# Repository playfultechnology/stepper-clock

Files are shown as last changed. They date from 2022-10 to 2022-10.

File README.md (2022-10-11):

# stepper-clock
A clock mechanism in which hour and minute hands driven independently by two 28BJY-48 stepper motors

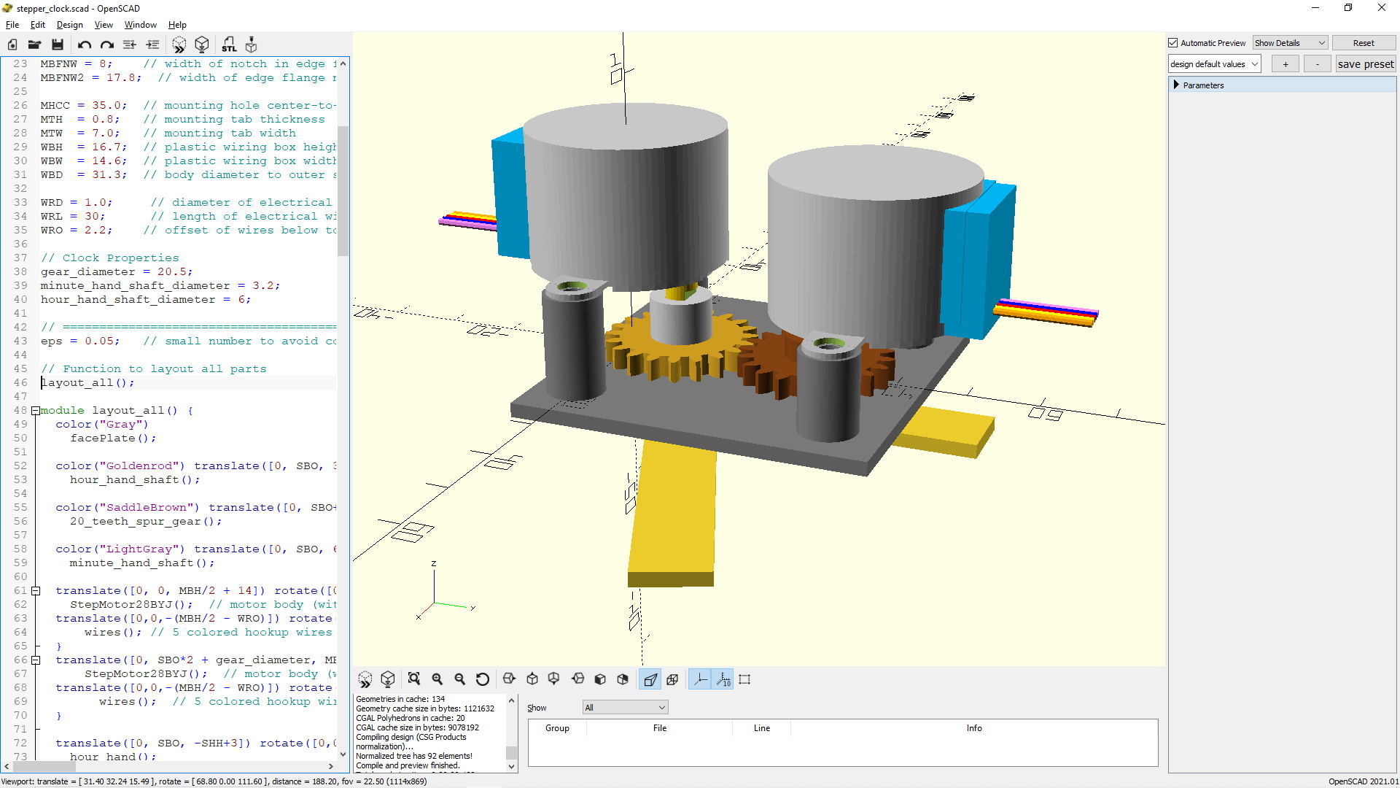
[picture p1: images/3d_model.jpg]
3D model


## Notes
28BJY-48 motors are very cheap, easy to source and use, and often found in hobbyist projects. They can be driven at 5V with 4 signal lines from an Arduino or other microprocessor via a ULN2003 driver. However, they have some noticeable limitations:
 - The gear ratio can differ between units; it generally seems to be either 4076 or 4096 steps per rotation. Note that neither of these numbers is exactly divisible by 360, nor 60, nor 12, so it is impossible to move the motor to an exact hour, minute, or degree of a circle.
 - Worse still, sometimes the gear ratio is not even a whole integer number of steps per revolution: meaning you cannot even rotate one full revolution accurately. 

These motors are intended for opening small vents in car air conditioning / heating systems. As such, they are not designed for continuous rotation, and accumulated error over multiple rotations is not considered a flaw in their design. However, that can present issues if you were trying to use these for accurate movement of clock hands. 
In my use case, this mechanism was for independent movement of hands in an escape room clock mechanism, so accuracy was not a crucial factor. For greater precision, it might be preferable to use a NEMA stepper instead which generally use exactly 200 steps per 360° degrees rotation - i.e. exactly 1.8° per step. However, they are significantly bulkier and more expensive.

Neither 28BJY-48 or NEMA17 stepper motors have any built-in position feedback mechanism. So, in order to be able to reset the hands to a known position, it might be desirable to add a small magnet to the cogs/hands, and a hall sensor to detect a "zero" point as they pass.

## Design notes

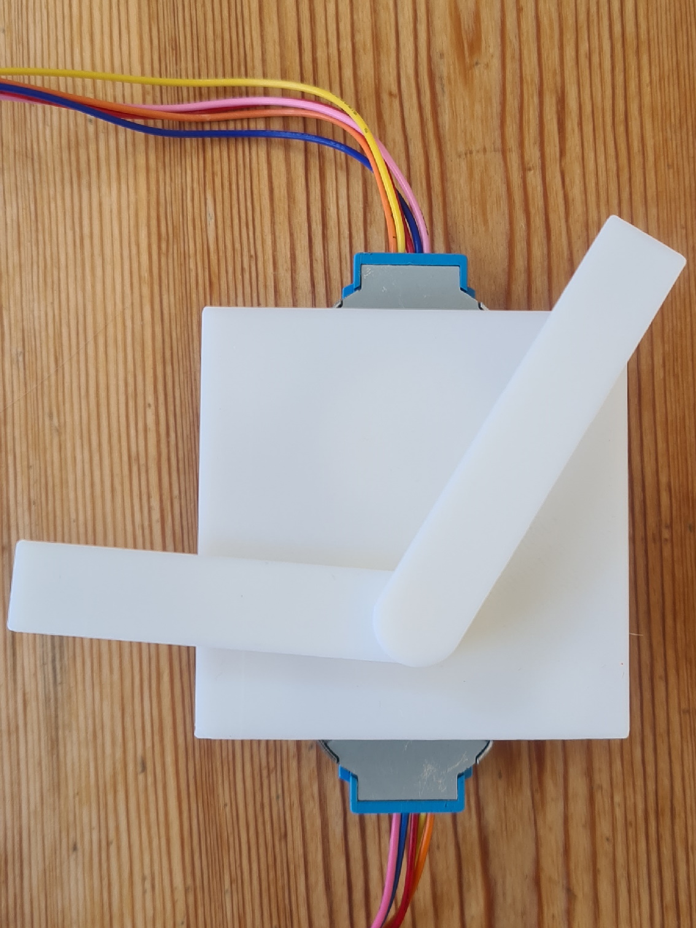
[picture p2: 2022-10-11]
images/clock.jpg

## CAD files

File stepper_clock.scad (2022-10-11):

/**
 * Stepper motor clock mechanism
 * (c) 2022 Alastair Aitchison, Playful Technology
 */

// Gear generator https://github.com/chrisspen/gears
// (English translation of https://www.thingiverse.com/thing:1604369)
include <gears/gears.scad>

// Stepper Motor Properties
MBH = 18.8;   // motor body height
MBD = 28.25;  // motor body OD
SBD = 9.1;    // shaft boss OD
SBH = 1.45;   // shaft boss height above motor body
SBO = 7.875;  // offset of shaft/boss center from motor center
SHD = 4.93;   // motor shaft OD
SHDF = 3.0;   // motor shaft diameter, across flats
SHHF = 6.0;   // motor shaft flats height, or depth in from end
SHH = 9.75;   // height of shaft above motor body 

MBFH = 0.7;   // height of body edge flange protruding above surface
MBFW = 1.0;   // width of edge flange
MBFNW = 8;    // width of notch in edge flange
MBFNW2 = 17.8;  // width of edge flange notch above wiring box

MHCC = 35.0;  // mounting hole center-to-center
MTH  = 0.8;   // mounting tab thickness
MTW  = 7.0;   // mounting tab width
WBH  = 16.7;  // plastic wiring box height
WBW  = 14.6;  // plastic wiring box width
WBD  = 31.3;  // body diameter to outer surface of wiring box

WRD = 1.0;     // diameter of electrical wires
WRL = 30;      // length of electrical wires
WRO = 2.2;		// offset of wires below top motor surface

// Clock Properties
gear_diameter = 20.5;
minute_hand_shaft_diameter = 3.2;
hour_hand_shaft_diameter = 6;

// =========================================================
eps = 0.05;   // small number to avoid coincident faces

// Function to layout all parts
layout_all();

module layout_all() {
  color("Gray")
    facePlate();

  color("Goldenrod") translate([0, SBO, 3]) rotate([0,180,0])
    hour_hand_shaft();
    
  color("SaddleBrown") translate([0, SBO+gear_diameter, 0]) rotate([0,0,0 -360/20/2 *3 ]) 
    20_teeth_spur_gear();

  color("LightGray") translate([0, SBO, 6+3]) rotate([0,180,90])
    minute_hand_shaft();
    
  translate([0, 0, MBH/2 + 14]) rotate([0, 0, 90]) {
    StepMotor28BYJ();  // motor body (without wires)
  translate([0,0,-(MBH/2 - WRO)]) rotate([0,-90,0])  
      wires(); // 5 colored hookup wires
  }
  translate([0, SBO*2 + gear_diameter, MBH/2 + 11]) rotate([0,0,-90]) {
      StepMotor28BYJ();  // motor body (without wires)
  translate([0,0,-(MBH/2 - WRO)]) rotate([0,-90,0])  
        wires();  // 5 colored hookup wires
  }
  
  translate([0, SBO, -SHH+3]) rotate([0,0,90])
    hour_hand();
  translate([0, SBO, -SHH]) rotate([0,0,22.5])
    minute_hand(); 
}


module minute_hand() {
  adjust = 0.1;
  hand_length = 50;
  
  difference(){
    union() {
      cylinder(d=10,h=4);
      translate([0,-5,0])
        cube([hand_length,10,2]);
    }
    translate([0,0,4-3])
    cylinder(d=minute_hand_shaft_diameter + adjust, h=3);
  }
}

module hour_hand() {
  adjust = -0.1;
  hand_length = 45;
  
  difference() {
    union() {
      cylinder(d=10,h=4);
      translate([0,-5,0])
        cube([hand_length,10,2]);
    }
    cylinder(d=hour_hand_shaft_diameter-1, h=4+eps);
    translate([0,0,0.4])
    cylinder(d=hour_hand_shaft_diameter + adjust, h=4-0.4+eps);
  }
}


module minute_hand_shaft() {
  expand = 0.15;
  shaft_depth = 5;

  difference() {
    union() {
      cylinder(d=8.9, h=6);
        translate([0,0,6])
          cylinder(d=3.2, h=12.5);
    }
    translate([0,0,-eps]) {
      intersection() {
        cylinder(d=SHD+expand, h=shaft_depth, $fn=40);
        translate([0,0, shaft_depth/2])
          cube([SHDF+expand,SHHF+expand,shaft_depth],center=true);
      }
    }
  }
}

module hour_hand_shaft() {
  difference() {
    union() {
      spur_gear (modul=1, tooth_number=20, width=3, bore=0, pressure_angle=20, helix_angle=0, optimized=false);
        translate([0,0,3])
          cylinder(d=6, h=6.5);
    }
    translate([0,0,-eps])
      cylinder(d=3.5, h=10);
  }
}

module 20_teeth_spur_gear() {
  expand = 0.1;
  shaft_depth = 5;
  
  difference() {
    union(){
      spur_gear (modul=1, tooth_number=20, width=3, bore=0, pressure_angle=20, helix_angle=0, optimized=false);
      translate([0,0,3]) {
        cylinder(d=8.9, h=3.05);
      }
    }
    translate([0,0,6.05-shaft_depth+eps])
      rotate([0,0,360/20/2*93])
        intersection() {
          cylinder(d=SHD+expand, h=shaft_depth, $fn=40);
            translate([0,0, shaft_depth/2])
            cube([SHDF+expand,SHHF+expand,shaft_depth],center=true);
        }
  }
}

module facePlate() {
  $fn=100;

  width= 50;
  length = 50;
  depth = 2;

  difference() {
    // Base
    translate([-width/2,-6,-depth])  
      cube([width,length,depth]);
    
    // Hole for shaft
    translate([0,SBO,-30]){
      cylinder(h=65, d=6.4);
    } 
  }
  // Standoffs
  translate([-MHCC/2, 0, 0]) {
    difference() {
      cylinder(h=14, d=8.1);
      cylinder(h=14+1, d=3);
    }
  }
  translate([MHCC/2, 0, 0]) {
    difference() {
      cylinder(h=14, d=8.1);
      cylinder(h=14+1, d=3);
    }
  }
  translate([-MHCC/2, SBO*2 + gear_diameter, 0]) {
    difference() {  
      cylinder(h=11, d=8.1);
      cylinder(h=11+1, d=3);
    }
  }
  translate([MHCC/2, SBO*2 + gear_diameter, 0]) {
    difference() {
      cylinder(h=11, d=8.1);
      cylinder(h=11+1, d=3);
    }
  }
}

// 28BYJ-48 model by RGriffoGoes, www.thingiverse.com/thing:204734
module StepMotor28BYJ() {
  difference(){
    union(){
	   color("LightGray") translate([0,0,-(MBH+MBFH)/2])
		  difference() {  // flange at top rim
         cylinder(h = MBFH+eps, r = MBD/2, center = true, $fn = 50);
         cylinder(h = MBFH+2*eps, r = (MBD-MBFW)/2, center = true, $fn = 32);
			cube([MBFNW,MHCC,MBFH*2],center=true); // notches in rim
			cube([MBD+2*MBFW,SBD,MBFH*2],center=true);
		   translate([-MBD/2,0,0]) cube([MBD,MBFNW2,MBFH*2],center=true);
        }
		color("LightGray") // motor body
			cylinder(h = MBH, r = MBD/2, center = true, $fn = 100);
		color("LightGray") translate([SBO,0,-SBH])	// shaft boss
			cylinder(h = MBH, r = SBD/2, center = true, $fn = 32);

		translate([SBO,0,-SHH])	// motor shaft
      difference() {
        color("gold") cylinder(h = MBH, r = SHD/2, center = true, $fn = 32);
				// shaft flats
        translate([(SHD+SHDF)/2,0,-(eps+MBH-SHHF)/2]) 
				cube([SHD,SHD,SHHF], center = true);
        translate([-(SHD+SHDF)/2,0,-(eps+MBH-SHHF)/2]) 
				cube([SHD,SHD,SHHF], center = true);
      }

		color("Silver") translate([0,0,-(MBH-MTH-eps)/2]) // mounting tab 
			cube([MTW,MHCC,MTH], center = true);				
		color("Silver") translate([0,MHCC/2,-(MBH-MTH)/2]) // mt.tab rounded end
			cylinder(h = MTH, r = MTW/2, center = true, $fn = 32);
		color("Silver") translate([0,-MHCC/2,-(MBH-MTH)/2]) // mt.tab rounded end
			cylinder(h = MTH, r = MTW/2, center = true, $fn = 32);

		color("DeepSkyBlue") translate([-(WBD-MBD),0,eps-(MBH-WBH)/2]) // plastic wire box
			cube([MBD,WBW,WBH], center = true);
	   color("DeepSkyBlue") translate([-2,0,0])	
			cube([24.5,16,15], center = true);
		}

    // mounting holes in tabs on side
		translate([0,MHCC/2,-MBH/2])	
				cylinder(h = 2, r = 2, center = true, $fn = 32);
		translate([0,-MHCC/2,-MBH/2])	
				cylinder(h = 2, r = 2, center = true, $fn = 32);
		}
	}
module wires() {
  color("orange") translate([0,WRD*2,0]) cylinder(h=WRL,r=WRD/2, $fn = 7);
  color("yellow") translate([0,WRD*1,0]) cylinder(h=WRL,r=WRD/2, $fn = 7);   
  color("red") translate([0,0,0]) cylinder(h=WRL,r=WRD/2, $fn = 7);
  color("blue") translate([0,-WRD*1,0]) cylinder(h=WRL,r=WRD/2, $fn = 7);
  color("violet") translate([0,-WRD*2,0]) cylinder(h=WRL,r=WRD/2, $fn = 7);
}  

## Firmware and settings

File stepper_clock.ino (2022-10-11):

// DEFINES
// Some discrepancy as to whether 4076 or 4096
// See https://www.makerguides.com/28byj-48-stepper-motor-arduino-tutorial/
#define NUM_STEPS 4096.0  
#define DEBUG

// INCLUDES
// https://www.airspayce.com/mikem/arduino/AccelStepper/
#include <AccelStepper.h>

// GLOBALS
// The 28BYJ-48 coils need to be energised in the pin sequence 1,3,2,4, rather than the standard 1,2,3,4 sequence
// In1, In3, In2, In4
AccelStepper hourStepper(AccelStepper::HALF4WIRE, 11, 9, 10, 8);
// Note the pin order for one pair is swapped for this motor as its direction is reversed through the gear train.
// In3, In1, In2, In4
AccelStepper minuteStepper(AccelStepper::HALF4WIRE, 5, 7, 6, 4);

void setup() {

  Serial.begin(115200);
  Serial.println(__FILE__ __DATE__);

  Serial.println(F("Send time in hh:mm format to set time"));
  Serial.println(F("Send H/h to +/-1 hour"));
  Serial.println(F("Send M/m to +/-1 minute"));
  Serial.println(F("Send - to set zero position"));
    

  // Configure each stepper
  hourStepper.setMaxSpeed(1000);
  minuteStepper.setMaxSpeed(1000);
  hourStepper.setAcceleration(500);
  minuteStepper.setAcceleration(500);
}

/**
 * Sets the target position of each hand based on supplied hours and minutes values
 * Note that this only sets the desired target - the actual movement is handled
 * in the main loop()
 */
void SetTime(long hours, long minutes){
  
    Serial.print("Setting time to ");
    Serial.print(hours);
    Serial.print(":");
    Serial.println(minutes);

  // There are 12 hours on one revolution of the clock face, so each hour requires NUM_STEPS / 12 steps
  hourStepper.moveTo(hours * (NUM_STEPS/12.0));
  // There are 60 minutes, so advancing one minute requires NUM_STEPS / 60 steps
  minuteStepper.moveTo(minutes * (NUM_STEPS/60.0));
}

/**
 * Checks and acts upon any input received on the serial connection
 */
void CheckSerialInput() {
    // Has any input has been received on the serial connection?
  if(Serial.available() > 0){
    // Define a character array to hold the received time data
    char data[6];
    // Count the number of bytes received
    int number_of_bytes_received;
    // Read data from the serial buffer into the timeData variable, until carriage return (or 5 bytes) is reached
    number_of_bytes_received = Serial.readBytesUntil('\r', data, 5);
    // Add a terminator to the end of the char array
    data[number_of_bytes_received] = 0;
    // If the character of data received was "-"
    if(memcmp(data, "-", 1) == 0){
      Serial.println("Setting zero position");
      hourStepper.setCurrentPosition(0);
      minuteStepper.setCurrentPosition(0);
    }
    // If the data character was "H", "h", "M", or "m", move the corresponding hand
    else if(memcmp(data, "h", 1) == 0) { hourStepper.move(-NUM_STEPS/12.0); }
    else if(memcmp(data, "H", 1) == 0) { hourStepper.move(NUM_STEPS/12.0); }
    else if(memcmp(data, "m", 1) == 0) { minuteStepper.move(-NUM_STEPS/60.0); }
    else if(memcmp(data, "M", 1) == 0) { minuteStepper.move(NUM_STEPS/60.0); }
    // Otherwise, set the hands based on the time assuming "hh:mm" format
    else {
      char *p = data;
      char *str;
      // Take the part of the time data up to the ":" token
      str = strtok_r(p, ":", &p);
      // Convert the tokenised string to a decimal number and save as "hours"
      long hours = strtol(str, NULL, 10);
      // Take the remaining part of the tokenised string
      str = strtok_r(NULL,":",&p);
      // Convert to a number and store as "minutes"
      long minutes = strtol(str, NULL, 10);
     
      // Set the hands' positions based on values received
      SetTime(hours,minutes);
    }
  }
}

void loop() {
    // Check for input via USB serial connection in format hh:mm
  CheckSerialInput();
  
  // We call the run() function on both steppers every frame, which processes any movement
  // required to reach their target position
  hourStepper.run();
  minuteStepper.run();
}
